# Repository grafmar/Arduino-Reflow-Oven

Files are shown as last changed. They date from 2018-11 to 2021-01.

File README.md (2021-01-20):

# Arduino-Reflow-Oven
This device controls a pizza oven to produce temperature ramps to use it as a [reflow oven](https://en.wikipedia.org/wiki/Reflow_oven). Therefore
several simple modifications are done. The builtin control is disconnected and the heater is controlled
through an opto-SSR (optocoupled solid state relay).

This reflow oven can therefore be used to produce a variety of temperature profiles - not only for reflow
soldering.

| The reflow oven | The Inside of the reflow oven |
| :--- | :--- |
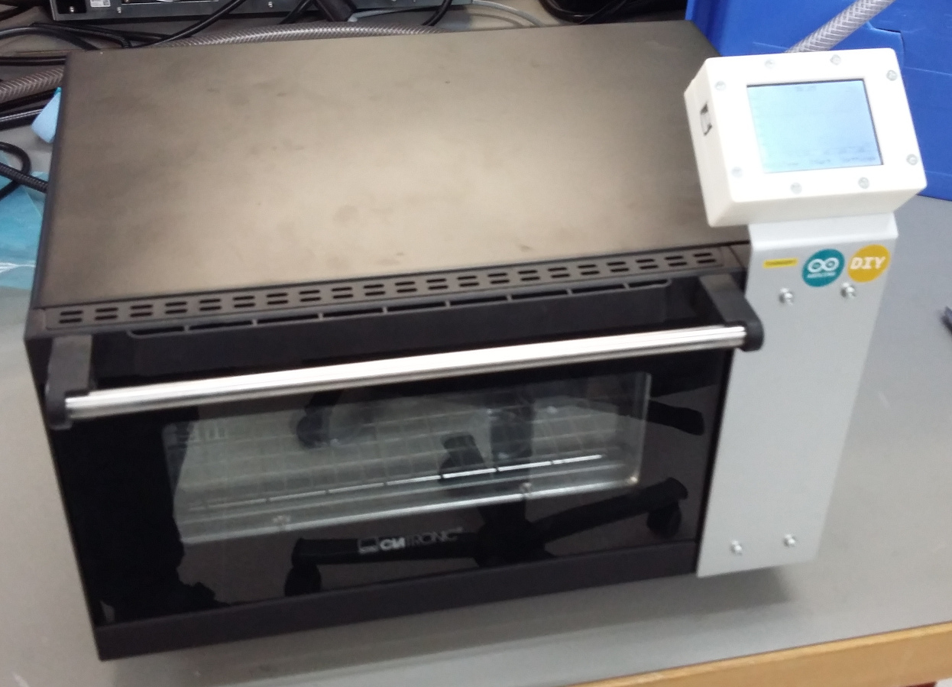
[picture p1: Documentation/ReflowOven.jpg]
Reflow Oven
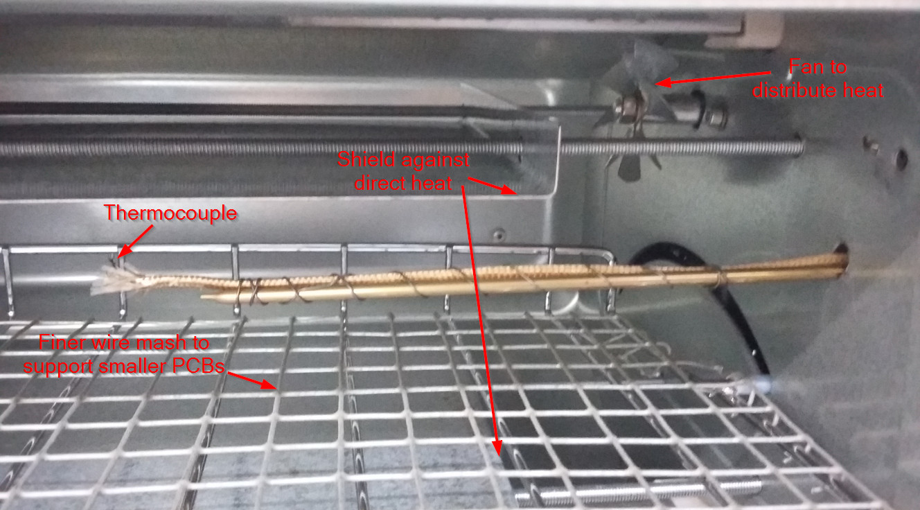
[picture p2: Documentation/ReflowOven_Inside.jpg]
Inside the Reflow Oven
|   |  |

## What is a reflow oven used to
To populate PCBs width components you could either use a soldering iron and solder each component by hand
or you can use a reflow oven. To use a reflow oven you put soldering paste onto the pads and put your
components on top. The you bake it in an oven - a reflow oven. The special functionality of a reflow oven
is that you can produce temperature profiles. This is to solder the components as gently as possible but
also guarantee good solder joints.

## Requirements
* [Arduino IDE](https://www.arduino.cc/en/main/software)
* Adafruit_GFX library (V1.5.0, newer libraries generate error according textsize)
* SWTFT Library
* TouchScreen Library
* MAX6675 Library
* TimerOne Library
* [Visual Studio](https://visualstudio.microsoft.com/) to have a comfortable IDE
* [Visual Micro](https://www.visualmicro.com/) to integrate Arduino IDE in Visual Studio

## Hardware
The hardware consists of:
* [Pizza oven Clatronic MPO 3520](https://www.clatronic.de/products/de/Elektro-Kleingeraete/Kleine-Backoefen/MPO-3520-Multi-Pizza-Ofen.html)
* [Arduino Uno](https://store.arduino.cc/arduino-uno-rev3)
* [2.4" 240x320 TFT display shield with integrated touch](https://www.aliexpress.com/item/ShengYang-1PCS-LCD-module-TFT-2-4-inch-TFT-LCD-screen-for-Arduino-UNO-R3-Board/32924291239.html)
* [Opto-SSR S202S02 / S202SE2](https://www.aliexpress.com/item/S202S02/32364561514.html)
* [MAX6675 thermocouple module with thermocouple sensor](https://www.aliexpress.com/item/2pcs-lot-MAX6675-K-type-Thermocouple-Temperature-Sensor-Temperature-0-800-Degrees-Module-Free-Shipping-Dropshipping/1843169664.html)

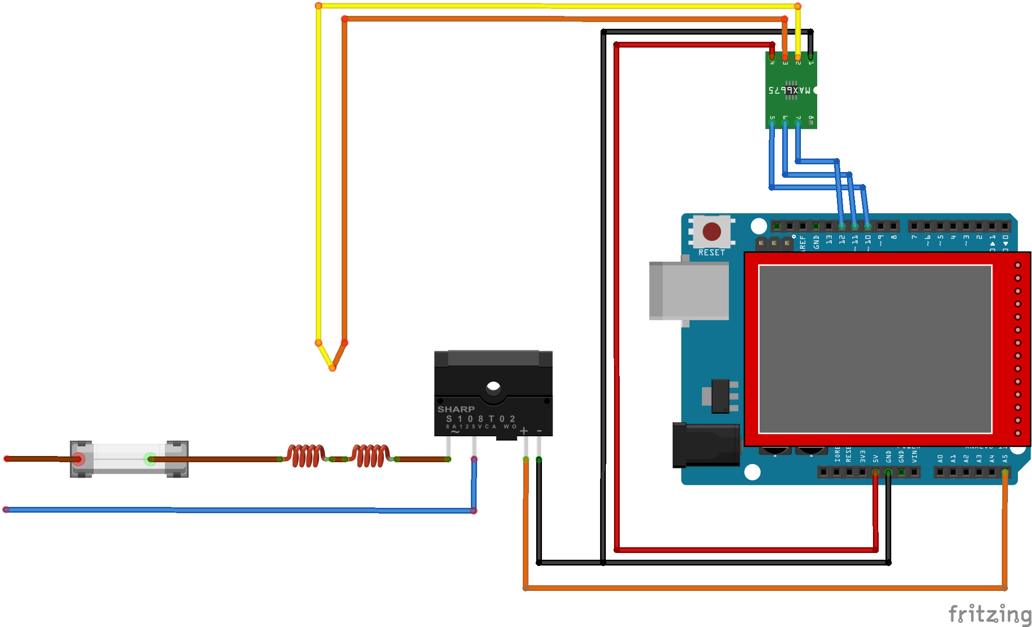
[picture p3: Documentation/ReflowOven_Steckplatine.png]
Reflow Oven Schematic


## Housing / Enclosure
The housing for the Arduino Uno and the TFT-Touch-Screen is printed using a 3D-Printer and mounted with a
piece of aluminium to the oven.

## Author
[Marco Graf](https://github.com/grafmar)  
Roman Scheuss

## Credits / Attribution
Roman Scheuss built this device and programmed the first version of the arduino code.

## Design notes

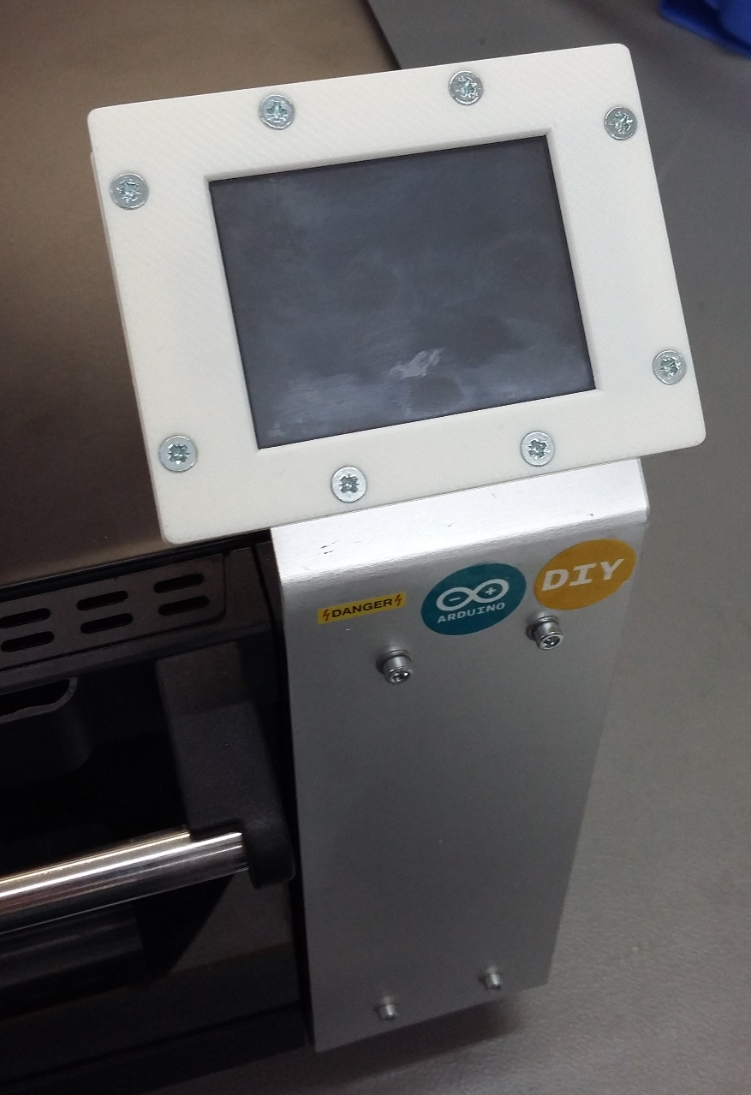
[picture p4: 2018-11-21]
Documentation/ReflowOven_Control.jpg

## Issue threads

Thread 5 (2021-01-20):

i cannot upload the code

LaurensMarkwat, 2021-01-20:
Dear Grafmar,

I am verry interrested in your project and would like to make it myself but when I want to upload the code to the arduino it does not work so could you help me?

kind regards,

Laurens Markwat

grafmar, 2021-01-20:
Hi Laurens,
What kind of display do you use?
in ReflowOven.h you can specify (line 9 and 10) one of two types:
- ST7781, which uses the SWTFT library included in the source
- SPFD5408, which uses the TftSpfd5408 library. This you have to install from Arduino-IDE->Sketch->Include Library->Manage Libraries

Best is if you can test your Display with a Library-Example and extend the ReflowOven.h file with the used pins and Touch parameters if needed.

kind regards,
  Marco Graf

grafmar, 2021-01-20:
Hi,

Okay, that was the hint needed ;-)
in "Adafruit GFX Library V1.5.0" there was a variable textsize. In the deriving classes SWTFT or TftSpfd5408 respectively this variable is initialized. Adafruit changed this to textsize_x and textsize_y.
So, get this working. Install Adafruit GFX Library V1.5.0 (this can be selected in the Library manager: search GFX, and in Adafruit GFX Library search in "Select version". Or you can update your driver-library by replacing in "TftSpfd5408.cpp" file the line `textsize  = 1;` in
```
textsize_x  = 1;
textsize_y  = 1;
```

kind regards,
  Marco Graf

LaurensMarkwat, 2021-01-20:
Thank you very much for your help. I have tried your suggestion and it is working. If I have further questions during the build I will contact you again. Thank you very much

Closed 2021-01-20.

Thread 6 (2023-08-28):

Display Link is not working

Littletitus, 2023-08-28:
The used link to the display is not working! I do have a Display here which looks like in the frizzing pic, but not sure if it’s the right one as the pins used for the temperature sensor are also used for an SD-card reader at the display! Uploaded the code, but only do get a white display without any text / infos…

grafmar, 2023-08-30:
Hi,
If you know which display driver chip you have you might adapt it.
please try to set the other driver in ReflowOven.h:

// Define the hardware: Original(ST7781 TFT) / my setup (SPFD5408 TFT)
#define USE_ST7781
//#define USE_SPFD5408

Otherwise you can replace the tft object in display.cpp with the one of your display driver:
// define the tft-object with the right library
#ifdef USE_ST7781
SWTFT tft;
#elif defined(USE_SPFD5408)
TftSpfd5408 tft(LCD_CS, LCD_CD, LCD_WR, LCD_RD, LCD_RESET);
#endif // USE_ST7781

grafmar, 2023-08-30:
Changed the link to a search link and added instructions to tweak the code. The search on aliexpress is not always working, but at least it is a hint.

Closed 2023-09-04.

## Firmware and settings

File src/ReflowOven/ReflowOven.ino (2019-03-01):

// Reflow Oven
//
// Arduino controlled reflow oven built by utilizing a mini oven. It has a TFT
// display with touch control and  thermocouple sensor to control the heating
// elements.
//
// Authors: Roman Scheuss, Marco Graf
// License: This project is licensed under the MIT License - see the LICENSE file for details

#include "ReflowOven.h"
#include "Display.h"
#include "EepromHandler.h"
#include "ProcessState.h"
#include "Setpoints.h"
#include "TouchButton.h"

#include <Adafruit_GFX.h>    // Core graphics library
#include <TouchScreen.h>
#include <EEPROM.h>
#include <max6675.h>


// generate objects
Setpoints setpoints;
ProcessState processState = ProcessState::Ready;

Display display(setpoints, processState);
TouchButton touchbutton;
MAX6675 thermocouple(thermoCLK, thermoCS, thermoDO);

TouchButton::ButtonId prevButton = TouchButton::noButton;
TouchButton::ButtonId actualInputSelection = TouchButton::buttonTemp;

uint16_t selectedTempPointValue = 0;
uint8_t selectedTempPoint = 0;

uint32_t lastMeasurementMS;
boolean timeToMeasure = false;

boolean heater = false;

uint16_t timeCounter = 0;
uint16_t preHeatTime = 12;
uint8_t saveIndex = 0;
String saveName = "";

void evaluateButton(TouchButton::ButtonId touchedButton);
void shiftNeightbourSetpoints(uint8_t setpointIndex);

void setup(void) {
    EepromHandler::loadSetpointSet(0, setpoints);   // loads hard
    if (!EepromHandler::isSetpointSetValid(0)) {
        EepromHandler::saveSetpointSet(0, setpoints);
    }

    // initialize serial communication
    Serial.begin(115200);
    Serial.print(F("ReflowOven Version V"));
    Serial.print(VERSION_MAJOR);
    Serial.print(F("."));
    Serial.println(VERSION_MINOR);

    // initialize heater pin
    pinMode(heaterPin, OUTPUT);

    // reset and start display
    display.begin();

    // draw homescreen
    display.drawHomeScreen();
    delay(1000);

    // EEPROM readout
    //for (uint16_t address=0; address < EEPROM.length(); address++) {
    //    if (address % 16 == 0) {
    //        Serial.println();
    //        char buffer[10];
    //        sprintf(buffer, "%04d:", address);
    //        Serial.print(buffer);
    //    }
    //    Serial.print(" ");
    //    Serial.print(EEPROM.read(address), HEX);
    //}

    lastMeasurementMS = millis();
}

//--------------------------------------------------------------------------------------------------------
void loop(void) {
    if ((millis() - lastMeasurementMS) >= 1000) {
        lastMeasurementMS += 1000;
        timeToMeasure = true;
    }

    if (timeToMeasure) {
        timeToMeasure = false;

        // read actual temperature
        double temp = thermocouple.readCelsius();

        // safety deadlock--!!!!!!!!!!!!!!!!!!!!!!!!!!!!!!!!!!!!!!!!!!!!!!!!!!!!!!!!!!!!!!!!!!!!!!!!!!!!!!!
        if ((temp > 300) || isnan(temp)) {
            digitalWrite(heaterPin, LOW);
            if (temp > 300) {
                display.drawErrorScreen(F("ERROR: TO HOT!!!"));
            }
            else {
                display.drawErrorScreen(F("FAIL SENSOR!!!"));
            }
            while (1);
        }
        //!!!!!!!!!!!!!!!!!!!!!!!!!!!!!!!!!!!!!!!!!!!!!!!!!!!!!!!!!!!!!!!!!!!!!!!!!!!!!!!!!!!!!!!!!!!!!!!!!

        if (processState == ProcessState::Running) {
            // to heat up during preheat time
            if (preHeatTime > 0) {
                heater = true;
                digitalWrite(heaterPin, HIGH);
                preHeatTime--;
                display.drawRemainingTime(preHeatTime);
            }

            // normal heat up
            else {
                uint16_t isTemperature = uint16_t(temp);

                // to turn on and off the heater if necessary
                if (isTemperature < calcSetpointValue(timeCounter)) {
                        heater = true;
                    digitalWrite(heaterPin, HIGH);
                }
                else {
                    heater = false;
                    digitalWrite(heaterPin, LOW);
                }

                // to terminate a reflow process
                if (timeCounter >= setpoints.sp[5].time) {
                    timeCounter = 0;
                    processState = ProcessState::Finished;
                    Serial.println(F("Finished"));
                    heater = false;
                    digitalWrite(heaterPin, LOW);
                    display.drawHomeScreen();
                }
                display.drawActualTemperatueChart(timeCounter, isTemperature);

                timeCounter++;
            }
        }

        if (display.getActualScreen() == Display::homeScreen) {
            display.drawActualTemp(temp, heater);
        }
    }
    
    if (display.getActualScreen() == Display::enterNameScreen) {
        char key = touchbutton.getTouchedKey();
        if (key != 0) {
            if (key == 127) {
                saveName = saveName.substring(0, saveName.length() - 1);
            } else {
                if (saveName.length() < 21) {
                    saveName += key;
                }
            }
            display.updateNameValue(saveName);
        }
    }

    TouchButton::ButtonId touchedButton = touchbutton.getTouchedButton(display.getActualScreen());
    evaluateButton(touchedButton);

    // check if still touched
    while (touchbutton.isTouched()) {
        delay(100);
    }

    delay(50);
}

void evaluateButton(TouchButton::ButtonId touchedButton) {
    if ((touchedButton != TouchButton::noButton) && (prevButton != touchedButton)) {   // is button pressed?
        switch (touchedButton) {
            case TouchButton::buttonBackSettings:   // fall through
            case TouchButton::buttonSettings:
                if (processState == ProcessState::Ready) {
                    display.drawSettingsScreen();
                } else {
                    //to block buttonSettings and buttonAboutInfo during reflow process and before press reset
                    Serial.println(F("Locked -> noAction"));
                }
                break;

            case TouchButton::buttonStartStopReset:
                if (processState == ProcessState::Ready) {
                    // start reflow process
                    processState = ProcessState::Running;
                    Serial.println(F("Running"));
                }
                else {
                    // reset reflow process
                    processState = ProcessState::Ready;
                    Serial.println(F("Ready"));
                    heater = false;
                    digitalWrite(heaterPin, LOW);
                    timeCounter = 0;
                    preHeatTime = 12;
                }
                display.drawHomeScreen();
                break;

            case TouchButton::buttonAboutInfo:
                if (processState == ProcessState::Ready) {
                    //Serial.println("buttonAboutInfo touched");
                    display.drawAboutInfoScreen();
                }
                else {
                    //to block buttonSettings and buttonAboutInfo during reflow process and before press reset
                    Serial.println(F("Locked -> noAction"));
                }
                break;

            case TouchButton::buttonBack:
                // Display::editSetpointsScreen or Display::aboutInfoScreen
                // Serial.println("buttonBack touched");
                display.drawHomeScreen();
                break;

            case TouchButton::buttonEdit:
                display.drawEditSetpointsScreen();
                break;

            case TouchButton::buttonLoad:
                display.drawLoadSetpointsScreen();
                break;

            case TouchButton::buttonSave:
                display.drawSaveSetpointsScreen();
                break;

            case TouchButton::buttonP1:
            case TouchButton::buttonP2:
            case TouchButton::buttonP3:
            case TouchButton::buttonP4:
            case TouchButton::buttonP5:
                //Serial.println("buttonP1-P5 touched");
                selectedTempPoint = 1 + static_cast<uint8_t>(touchedButton - TouchButton::buttonP1);
                display.drawSetpointInputScreen(actualInputSelection == TouchButton::buttonTemp, selectedTempPoint, selectedTempPointValue);
                break;

            case TouchButton::button0:
            case TouchButton::button1:
            case TouchButton::button2:
            case TouchButton::button3:
            case TouchButton::button4:
            case TouchButton::button5:
            case TouchButton::button6:
            case TouchButton::button7:
            case TouchButton::button8:
            case TouchButton::button9:
            {
                //Serial.println("button0-button9 touched");
                uint32_t value = selectedTempPointValue;
                value = value * 10U + static_cast<uint8_t>(touchedButton - TouchButton::button0);

                if (((value <= MAX_SETPOINT_TIME) && (actualInputSelection == TouchButton::buttonTime))  
                    || ((value <= MAX_SETPOINT_TEMPERATURE) && (actualInputSelection == TouchButton::buttonTemp))) {

                    selectedTempPointValue = static_cast<uint16_t>(value);
                    display.drawTempPointValueScreen(selectedTempPointValue);
                }
                break;
            }
            case TouchButton::buttonDel:
                //Serial.println("buttonDel touched");
                selectedTempPointValue = selectedTempPointValue / 10U;
                display.drawTempPointValueScreen(selectedTempPointValue);
                break;

            case TouchButton::buttonOK:
                //Serial.println("buttonOK touched");
                if (actualInputSelection == TouchButton::buttonTime) {
                    if (selectedTempPointValue < 1U) {
                        selectedTempPointValue = 1U;
                    }
                    setpoints.sp[selectedTempPoint].time = selectedTempPointValue;
                    shiftNeightbourSetpoints(selectedTempPoint);
                }
                else {
                    setpoints.sp[selectedTempPoint].temperature = selectedTempPointValue;
                }

                display.drawEditSetpointsScreen();
                break;

            case TouchButton::buttonTemp:
                //Serial.println("buttonTemp touched");
                actualInputSelection = TouchButton::buttonTemp;
                display.drawSetpointInputScreen(actualInputSelection == TouchButton::buttonTemp, selectedTempPoint, selectedTempPointValue);
                break;

            case TouchButton::buttonTime:
                //Serial.println("buttonTime touched");
                actualInputSelection = TouchButton::buttonTime;
                display.drawSetpointInputScreen(actualInputSelection == TouchButton::buttonTemp, selectedTempPoint, selectedTempPointValue);
                break;

            case TouchButton::buttonDefault:
            case TouchButton::buttonM1:
            case TouchButton::buttonM2:
            case TouchButton::buttonM3:
            case TouchButton::buttonM4:
            case TouchButton::buttonM5:
            {
                uint8_t index = static_cast<uint8_t>(touchedButton - TouchButton::buttonDefault);
                if (display.getActualScreen() == Display::loadSetpointsScreen) {
                    if (EepromHandler::isSetpointSetValid(index)) {
                        EepromHandler::loadSetpointSet(index, setpoints);
                        display.drawSettingsScreen();
                    }
                } else {
                    saveIndex = index;
                    saveName = setpoints.name;
                    display.drawEnterNameScreen(saveName);
                }
                break;
            }

            case TouchButton::buttonSaveAs:
                memset(setpoints.name, 0U, setpoints.NAME_LENGTH);            // clear name string in setpoints
                memcpy(setpoints.name, saveName.c_str(), saveName.length());    // copy string to name in setpoints
                EepromHandler::saveSetpointSet(saveIndex, setpoints);
                display.drawSettingsScreen();
                break;

            case TouchButton::noButton:
            default:
                break;
        }
    }

    prevButton = touchedButton;
}


/**
* This function calculates the interpolated temperature setpoint at the given time.
* @param time the time value to calculate the temperatue setpoint of.
* @return the calculated temperature setpoint.
*/
uint16_t calcSetpointValue(uint16_t time) {
    for (uint8_t i=1; i < Setpoints::NUM_OF_SETPOINTS; i++) {
        if (time <= setpoints.sp[i].time) {
            //Serial.print(i);
            //Serial.print(", ");
            //Serial.print(time);
            //Serial.print(", ");
            //Serial.println(map(time, setpoints.sp[i - 1].time, setpoints.sp[i].time, setpoints.sp[i - 1].temperature, setpoints.sp[i].temperature));
            return map(time, setpoints.sp[i-1].time, setpoints.sp[i].time, setpoints.sp[i-1].temperature, setpoints.sp[i].temperature);
        }
    }
    return 0; // just in case we get here
}


/**
* Shifts the time of the neighbouring setpoints so the time of the setpoints does not overrung each other (time will be in ascending order).
* @param setpointIndex the index of the adjusted setpoint.
*/
void shiftNeightbourSetpoints(uint8_t setpointIndex) {
    for (uint8_t i=setpointIndex; i > 0; i--) {
        if (setpoints.sp[i - 1].time > setpoints.sp[i].time) {
            setpoints.sp[i - 1].time = setpoints.sp[i].time;
        }
    }
    for (uint8_t i=setpointIndex; i < Setpoints::NUM_OF_SETPOINTS-1; i++) {
        if (setpoints.sp[i + 1].time < setpoints.sp[i].time) {
            setpoints.sp[i + 1].time = setpoints.sp[i].time;
        }
    }
}

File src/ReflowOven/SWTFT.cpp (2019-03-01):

// Code provided by Smoke And Wires
// http://www.smokeandwires.co.nz
// This code has been taken from the Adafruit TFT Library and modified
//  by us for use with our TFT Shields / Modules
// For original code / licensing please refer to
// https://github.com/adafruit/TFTLCD-Library

#include <avr/pgmspace.h>

#include "pins_arduino.h"
#include "wiring_private.h"
#include "SWTFT.h"

// Use the include which corresponde to your arduino
//#include "mega_24_shield.h"
#include "uno_24_shield.h"


#define TFTWIDTH   240
#define TFTHEIGHT  320
#define swap(a, b) { int16_t t = a; a = b; b = t; }

// Constructor for breakout board (configurable LCD control lines).
// Can still use this w/shield, but parameters are ignored.
SWTFT::SWTFT() :  Adafruit_GFX(TFTWIDTH, TFTHEIGHT) {


  // Convert pin numbers to registers and bitmasks
  _reset     = LCD_RESET;
 
    csPort     = portOutputRegister(digitalPinToPort(LCD_CS));
    cdPort     = portOutputRegister(digitalPinToPort(LCD_CD));
    wrPort     = portOutputRegister(digitalPinToPort(LCD_WR));
    rdPort     = portOutputRegister(digitalPinToPort(LCD_RD));

  csPinSet   = digitalPinToBitMask(LCD_CS);
  cdPinSet   = digitalPinToBitMask(LCD_CD);
  wrPinSet   = digitalPinToBitMask(LCD_WR);
  rdPinSet   = digitalPinToBitMask(LCD_RD);
  csPinUnset = ~csPinSet;
  cdPinUnset = ~cdPinSet;
  wrPinUnset = ~wrPinSet;
  rdPinUnset = ~rdPinSet;

    *csPort   |=  csPinSet; // Set all control bits to HIGH (idle)
    *cdPort   |=  cdPinSet; // Signals are ACTIVE LOW
    *wrPort   |=  wrPinSet;
    *rdPort   |=  rdPinSet;
 
  pinMode(LCD_CS, OUTPUT);    // Enable outputs
  pinMode(LCD_CD, OUTPUT);
  pinMode(LCD_WR, OUTPUT);
  pinMode(LCD_RD, OUTPUT);
//  if(reset) {
    digitalWrite(LCD_RESET, HIGH);
    pinMode(LCD_RESET, OUTPUT);
 // }


  init();
}


void SWTFT::init(void) {
  setWriteDir(); // Set up LCD data port(s) for WRITE operations

  rotation  = 0;
  cursor_y  = cursor_x = 0;
  textsize  = 1;
  textcolor = 0xFFFF;
  _width    = TFTWIDTH;
  _height   = TFTHEIGHT;
}

// // Initialization command table for LCD controller
 #define TFTLCD_DELAY 0xFF

static const uint16_t ST7781_regValues[] PROGMEM = {
 0x0001,0x0100,    
 0x0002,0x0700,    
0x0003,0x1030,    
0x0008,0x0302,    
0x0009,0x0000,   
0x000A,0x0008,    
//*******POWER CONTROL REGISTER INITIAL*******//    
0x0010,0x0790,    
0x0011,0x0005,    
0x0012,0x0000,   
0x0013,0x0000,    
 //delayms(50, 
//********POWER SUPPPLY STARTUP 1 SETTING*******//    
0x0010,0x12B0,    
// delayms(50,  
0x0011,0x0007,    
 //delayms(50,  
//********POWER SUPPLY STARTUP 2 SETTING******//    
0x0012,0x008C,    
0x0013,0x1700,    
0x0029,0x0022,    
// delayms(50,   
//******GAMMA CLUSTER SETTING******//    
0x0030,0x0000,    
0x0031,0x0505,    
0x0032,0x0205,    
0x0035,0x0206,    
0x0036,0x0408,    
0x0037,0x0000,    
0x0038,0x0504,
0x0039,0x0206,    
0x003C,0x0206,    
0x003D,0x0408,    
// -----------DISPLAY WINDOWS 240*320-------------//    
0x0050,0x0000,
0x0051,0x00EF,   
0x0052,0x0000,   
0x0053,0x013F,   
//-----FRAME RATE SETTING-------//    
0x0060,0xA700,   
0x0061,0x0001,   
0x0090,0x0033, //RTNI setting
//-------DISPLAY ON------//    
0x0007,0x0133,    0x0001,0x0100,    
 0x0002,0x0700,    
0x0003,0x1030,    
0x0008,0x0302,    
0x0009,0x0000,   
0x000A,0x0008,    
//*******POWER CONTROL REGISTER INITIAL*******//    
0x0010,0x0790,    
0x0011,0x0005,    
0x0012,0x0000,   
0x0013,0x0000,    
 //delayms(50, 
//********POWER SUPPPLY STARTUP 1 SETTING*******//    
0x0010,0x12B0,    
// delayms(50,  
0x0011,0x0007,    
// delayms(50,  
//********POWER SUPPLY STARTUP 2 SETTING******//    
0x0012,0x008C,    
0x0013,0x1700,    
0x0029,0x0022,    
// delayms(50,   
//******GAMMA CLUSTER SETTING******//    
0x0030,0x0000,    
0x0031,0x0505,    
0x0032,0x0205,    
0x0035,0x0206,    
0x0036,0x0408,    
0x0037,0x0000,    
0x0038,0x0504,
0x0039,0x0206,    
0x003C,0x0206,    
0x003D,0x0408,    
// -----------DISPLAY WINDOWS 240*320-------------//    
0x0050,0x0000,
0x0051,0x00EF,   
0x0052,0x0000,   
0x0053,0x013F,   
//-----FRAME RATE SETTING-------//    
0x0060,0xA700,   
0x0061,0x0001,   
0x0090,0x0033, //RTNI setting
//-------DISPLAY ON------//    
0x0007,0x0133,   
};

void SWTFT::begin(uint16_t id) {
  uint8_t i = 0;

  reset();

 

    uint16_t a, d;
//    driver = ID_932X;
    CS_ACTIVE;
    while(i < sizeof(ST7781_regValues) / sizeof(uint16_t)) {
      a = pgm_read_word(&ST7781_regValues[i++]);
      d = pgm_read_word(&ST7781_regValues[i++]);
      if(a == TFTLCD_DELAY) delay(d);
      else                  writeRegister16(a, d);
    }
    setRotation(rotation);
    setAddrWindow(0, 0, TFTWIDTH-1, TFTHEIGHT-1);

  
}

void SWTFT::reset(void) {

  CS_IDLE;
//  CD_DATA;
  WR_IDLE;
  RD_IDLE;


  if(_reset) {
    digitalWrite(_reset, LOW);
    delay(2);
    digitalWrite(_reset, HIGH);
  }


  // Data transfer sync
  CS_ACTIVE;
  CD_COMMAND;
  write8(0x00);
  for(uint8_t i=0; i<3; i++) WR_STROBE; // Three extra 0x00s
  CS_IDLE;
}

// Sets the LCD address window (and address counter, on 932X).
// Relevant to rect/screen fills and H/V lines.  Input coordinates are
// assumed pre-sorted (e.g. x2 >= x1).
void SWTFT::setAddrWindow(int x1, int y1, int x2, int y2) {

  CS_ACTIVE;
  
    // Values passed are in current (possibly rotated) coordinate
    // system.  932X requires hardware-native coords regardless of
    // MADCTL, so rotate inputs as needed.  The address counter is
    // set to the top-left corner -- although fill operations can be
    // done in any direction, the current screen rotation is applied
    // because some users find it disconcerting when a fill does not
    // occur top-to-bottom.
    int x, y, t;
    switch(rotation) {
     default:
      x  = x1;
      y  = y1;
      break;
     case 1:
      t  = y1;
      y1 = x1;
      x1 = TFTWIDTH  - 1 - y2;
      y2 = x2;
      x2 = TFTWIDTH  - 1 - t;
      x  = x2;
      y  = y1;
      break;
     case 2:
      t  = x1;
      x1 = TFTWIDTH  - 1 - x2;
      x2 = TFTWIDTH  - 1 - t;
      t  = y1;
      y1 = TFTHEIGHT - 1 - y2;
      y2 = TFTHEIGHT - 1 - t;
      x  = x2;
      y  = y2;
      break;
     case 3:
      t  = x1;
      x1 = y1;
      y1 = TFTHEIGHT - 1 - x2;
      x2 = y2;
      y2 = TFTHEIGHT - 1 - t;
      x  = x1;
      y  = y2;
      break;
    }
    writeRegister16(0x0050, x1); // Set address window
    writeRegister16(0x0051, x2);
    writeRegister16(0x0052, y1);
    writeRegister16(0x0053, y2);
    writeRegister16(0x0020, x ); // Set address counter to top left
    writeRegister16(0x0021, y );

  
  CS_IDLE;
}
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

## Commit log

2019-02-04 Some cleanup and optimization. removed TimerOne-usage
2019-02-15 Added header file and defined procompiler variables to switch between two different TFTs
2019-02-17 Renamed Arduino project to "ReflowOven"
2019-02-17 Created VisualStudio Project using "arduino for visual studio" of visualmicro.com
2019-02-18 Created TouchButton class to evaluate the touch events to button events
2019-02-21 Created TouchButton class and stored button coordinates as structs in PROGMEM (Flash)
2019-02-21 refactored button handling into evaluateButton() optimized button evaluation
2019-02-21 removed istTemp-array and actualizing temperature sample by sample -> not redrawing the whole display Introduced the process state instead of two booleans
2019-02-22 Set version to V1.2 using precompiler variables Connecting the actual temperature values in the chart
2019-02-24 Maximizing the chart the the last setpoints time (stretch X-axis)
2019-02-25 dynamic time tics calculation time range up to 65535s and limiting to minimum 1s setpoint entering limitting optimized applied check and correction for ascending setpoint times
    [ReflowOven.h, ReflowOven.ino]
2019-02-26 Implemented drawing of buttons based on touch button coordinates Added Settings menu Renamed screen-ID names Created Setpoints struct with all setpoints in it
2019-03-01 Set for Display of real reflow oven correction to save default setting if no setting in EEPROM
    [ReflowOven.h, ReflowOven.ino]
2019-03-01 Touch filter changed again
2019-03-01 Bugfix when shortening the profile names
    [ReflowOven.ino]
2019-03-01 Added Fritzing Schematic
    [ReflowOven.fzz]
2019-03-01 Update README.md
    Added Schematic to readme
